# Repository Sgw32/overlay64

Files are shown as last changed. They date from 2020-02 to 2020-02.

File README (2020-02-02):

overlay64 - video overlay module

!!!SMD version!!!

This SMD version has reduced cost of manufacturing, since DIP Atmegas are rare and expensive. 
Also changed THD resistors to SMD 0805, suitable for soldering by hand.

The overlay64 module allows superimposing predefined texts onto an
existing composite signal or onto the luminance portion of an s-video
signal depending on the states of up to sixteen digital input
lines. An LM1881 video sync separator IC is used to detect the
vertical and horizontal sync pulses of the video signal. An Atmega1284
uses these signals to synchronize with the video signal and to
superimpose text on the video display by bit-banging the corresponding
characters over SPI.

The user writes a simple configuration file that determines which
texts are to be displayed for which input line states. The
configuration file is converted to a binary format using the supplied
commandline tool before flashing it to the Atmegas's eeprom memory via
the USB interface.

Possible uses include displaying the state of control lines for
additional hardware installed in a homecomputer such as the Commodore
64, for example to display the currently selected kernal based on the
state of the control lines for a multi-kernal adapter.

An early working prototype can be seen in this video where it displays
the runtime configuration of the MixSID Stereo SID board:

https://www.youtube.com/watch?v=0exp2yM0WHM

This repository includes the complete sourcecode of the client
software, the firmware and all design files in KiCAD format.

LICENSING

Hardware licenced under CERN OHL v.1.2, see ./hardware/LICENSE.txt
Software and firmware licenced under GNU GPLv3, see ./LICENSE

The software contains MIT licensed code from
https://github.com/arkku/ihex for reading Intel HEX files, Copyright
(c) 2013-2015 Kimmo Kulovesi, see ./intelhex/LICENSE

The firmware contains the V-USB Driver (https://www.obdev.at/vusb),
(C)2008 Objective Development GmbH.

Distributed in the ./bootloader directory is the USBasp bootloader,
(C)2013 Stephan Baerwolf (matrixstorm@gmx.de) and (C)2008 Objective
Development GmbH (https://www.obdev.at/vusb).

In compliance with the terms of the (identical) V-USB driver and
USBasp bootloader licenses (./firmware/usbdrv/License.txt and
./bootloader/License.txt), the entire project is published under

http://www.henning-bekel.de/overlay64

In addition, this distribution contains

- a circuit diagram in PDF format, see ./hardware/overlay64-schematics.pdf
- the full source code for the host software in ./firmware
- this README file
- references to https://www.obdev.at/vusb

The USB Product and Vendor IDs for the Overlay64 USB device have kindly
been provided by OpenMoko, Inc (http://openmoko.org).

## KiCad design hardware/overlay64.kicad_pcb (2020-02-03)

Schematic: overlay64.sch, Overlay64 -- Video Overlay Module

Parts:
C1, C4, C5, C6: 100nF; C_Disc_D3_P2.5
C2, C3: 18pF; C_Disc_D3_P2.5
D1, D2: 3.6V; D3
IC1: ATmega1284P-AU; TQFP-44_10x10mm_P0.8mm
J: USB_B_Mini; USB_Mini-B_Lumberg_2486_01_Horizontal
P2: INPUT; Pin_Header_Angled_1x16
P3: CONTROL; Pin_Header_Angled_1x08
P4: MAIN; Pin_Header_Angled_1x03
P5, P6, P7, P8: HOLE; MountingHole_4mm
P9: BYPASS; Pin_Header_Angled_1x16
R1, R2: 68; R3
R3: 1k5; R3
R5: 680k; R3
RV1: 1k; Potentiometer_Bourns_3339P_Angular_ScrewUp
U1: LM1881; DIP-8_W7.62mm
Y1: 20MHz; Crystal_HC49-U_Vertical

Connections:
/BOOT: IC1.9
/C0: IC1.15, P3.8
/C1: IC1.16, P3.7
/C2: IC1.41, P3.6
/C3: IC1.43, P3.5
/C4: IC1.2, P3.4
/C5: IC1.3, P3.3
/C6: IC1.13, P3.2
/C7: IC1.14, P3.1
/D+: D2.1 (K), R2.1; also elsewhere on the board
/D-: D1.1 (K), R1.1, R3.1; also elsewhere on the board
/IN0: IC1.37, P2.16, P9.1
/IN1: IC1.36, P2.15, P9.2
/IN2: IC1.35, P2.14, P9.3
/IN3: IC1.34, P2.13, P9.4
/IN4: IC1.33, P2.12, P9.5
/IN5: IC1.32, P2.11, P9.6
/IN6: IC1.31, P2.10, P9.7
/IN7: IC1.30, P2.9, P9.8
/IN8: IC1.26, P2.8, P9.9
/IN9: IC1.25, P2.7, P9.10
/IN10: IC1.24, P2.6, P9.11
/IN11: IC1.23, P2.5, P9.12
/IN12: IC1.22, P2.4, P9.13
/IN13: IC1.21, P2.3, P9.14
/IN14: IC1.20, P2.2, P9.15
/IN15: IC1.19, P2.1, P9.16
/LUMA: C4.1, P4.2, RV1.3
/MOSI: IC1.1, RV1.2
/~BURST: IC1.42, U1.5
/~HSYNC: IC1.40, U1.1
/~VSYNC: IC1.12, U1.3
unnamed: C2.2, IC1.8, Y1.1
unnamed: C3.2, IC1.7, Y1.2
unnamed: C4.2, U1.2
unnamed: C5.1, R5.1, U1.6
unnamed: IC1.10, R1.2
unnamed: IC1.11, R2.2
VCC: C1.1, C6.1, IC1.5, IC1.17, IC1.27, IC1.38, P4.1, R3.2, U1.8

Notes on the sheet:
Overlay64 video overlay module Copyright 2016 Henning Bekel This documentation describes Open Hardware and is licensed under the CERN OHL v. 1.2. You may redistribute and modify this documentation under the terms of the CERN OHL v.1.2. (http://ohwr.org/cernohl). This documentation is distributed WI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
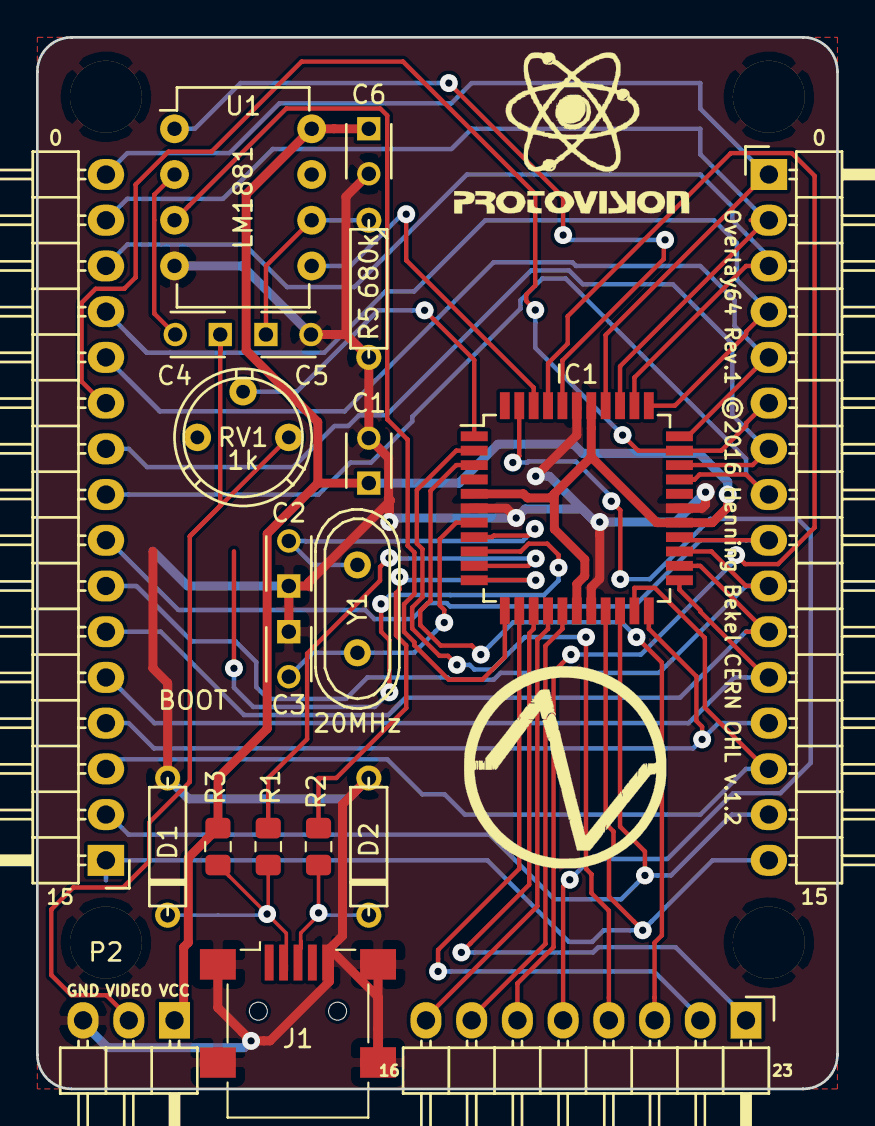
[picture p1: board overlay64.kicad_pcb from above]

Board: 2 copper layers, 44.5 x 58.4 mm, 25 parts (0 on the bottom side), 39 nets.

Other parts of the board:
J1: USB_B_Mini; USB_Mini-B_Lumberg_2486_01_Horizontal

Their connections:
/D+: J1.3; also elsewhere on the board
/D-: J1.2; also elsewhere on the board

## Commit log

2020-02-02 SMD rework
    [overlay64.kicad_pcb, overlay64.sch]
2020-02-03 Add logos
    [overlay64.kicad_pcb]

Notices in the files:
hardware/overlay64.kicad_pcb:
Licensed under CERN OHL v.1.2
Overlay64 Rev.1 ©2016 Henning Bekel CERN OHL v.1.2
